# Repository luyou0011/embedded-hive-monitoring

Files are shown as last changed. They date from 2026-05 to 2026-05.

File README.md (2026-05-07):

# Entwicklung eines Embedded Systems zur automatischen Messdatenerfassung in Bienenstöcken

Diese Bachelorarbeit befasst sich mit der Entwicklung eines IoT-basierten Monitoring-Systems für Bienenvölker. Das System überwacht Klima, Gewicht und Akustik, um die Gesundheit der Bienen zu sichern und die Honigproduktion zu optimieren.

<p align="center">
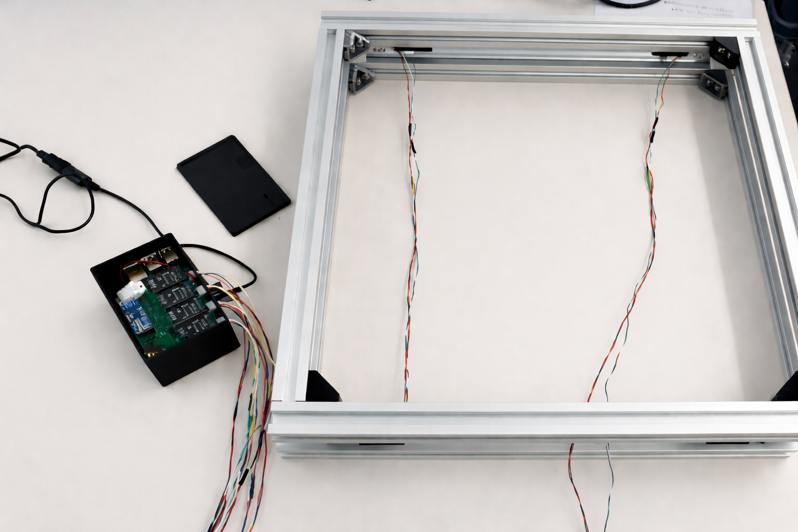
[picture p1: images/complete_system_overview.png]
Komplettes System
  
  <br>
  <em>Das fertige Monitoring-System mit Aluminiumprofil-Basis und integrierter Steuerelektronik.</em>
</p>

## Features & Funktionen
- **Multisensorik:** Präzise Echtzeit-Messung von Temperatur, Luftfeuchtigkeit (DHT22) und Gewicht (HX711).
- **Fortgeschrittene Akustik-Analyse:** Aufzeichnung von Bienengeräuschen mittels I2S-Mikrofon und digitale Frequenzfilterung (200 Hz - 1000 Hz) zur Zustandsüberwachung.
- **Energie-Monitoring:** Integrierte Überwachung des Batteriezustands (SoC) über einen ADS1115 16-Bit ADC.
- **Intelligente Datenlogik:** Event-gesteuerte Übertragung zur Reduzierung des Datenvolumens und Optimierung der Energieeffizienz.

## Hardware-Entwicklung & Design
Ein zentraler Bestandteil der Arbeit war der Übergang vom Breadboard-Prototyp zum finalen Hardware-Produkt:
- **Custom PCB:** Entwurf und Fertigung einer dedizierten Platine mit **KiCAD 8.0**.
- **Gehäusekonstruktion:** Maßgeschneidertes Schutzgehäuse, entworfen in **Autodesk Fusion**.
- **Recheneinheit:** Raspberry Pi 4B.
- **Sensorkomponenten:** DHT22 (Temperatur und Feuchtigkeit Sensor), SPH0645 (I2S Mikrofon), HX711 (24-Bit Load Cell ADC), ADS1115.

## Software & Cloud-Architektur
- **Programmiersprache:** Python (Modularer Aufbau für Sensorik und Kommunikation).
- **IoT-Integration:** 
  - **ThingSpeak:** Cloud-Visualisierung der Klima- und Gewichtsdaten.
  - **AWS IoT Core:** Sicherer MQTT-Transfer für rechenintensive Audiodaten.
- **Kommunikation:** Nutzung von TCP-Sockets für die Interprozesskommunikation.

## Mobile App (Android)
Die Überwachung erfolgt über eine maßgeschneiderte Android-App. Sie dient als mobiles Dashboard für den Imker und ermöglicht den weltweiten Zugriff auf alle Live-Daten.

<p align="center">
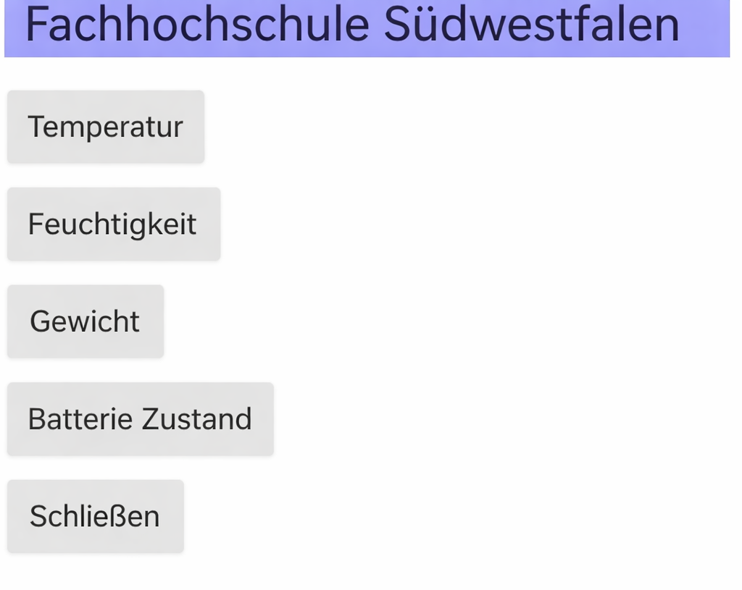
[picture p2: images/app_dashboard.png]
App Dashboard
  
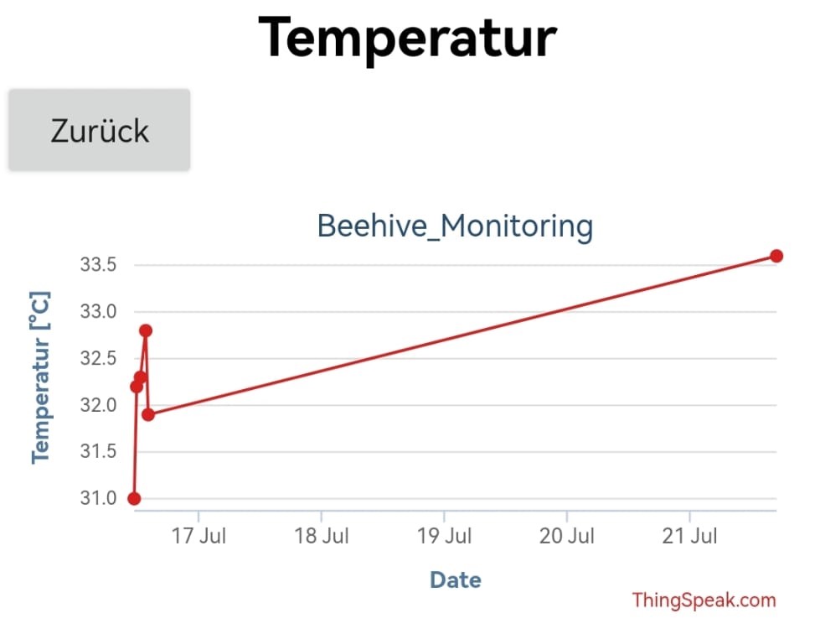
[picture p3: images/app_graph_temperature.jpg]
Temperatur Graph
  
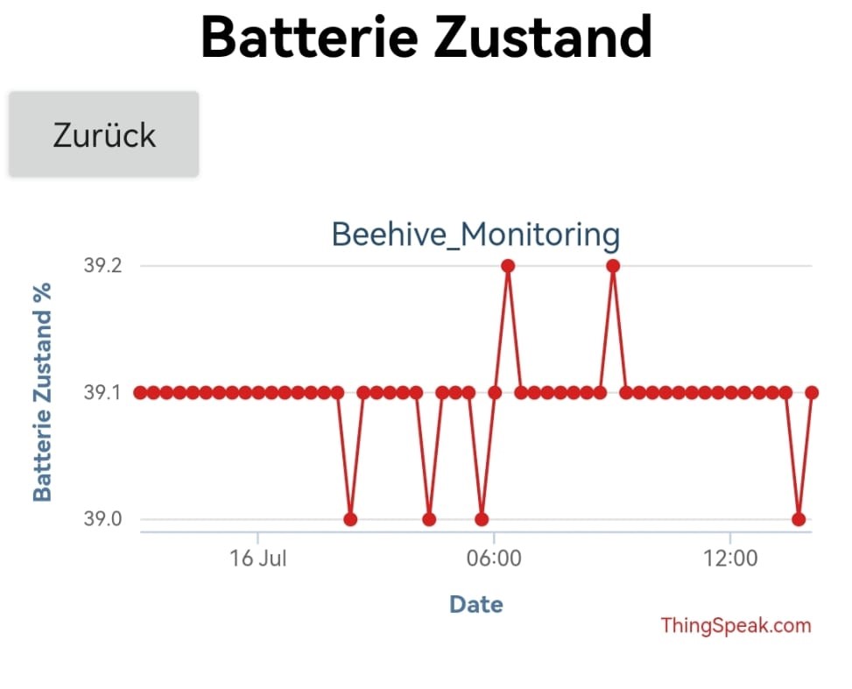
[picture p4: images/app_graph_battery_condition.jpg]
Batterie Zustand
  
  <br>
  <em>Screenshots der mobilen App: Dashboard, Temperaturverlauf und Batteriemonitoring.</em>
</p>

## Projektergebnisse
Das System wurde erfolgreich als autarke Einheit realisiert. Durch das eigene Platinenlayout wurde eine hohe Betriebssicherheit erreicht. Die Daten stehen dem Imker weltweit über Dashboards und eine Android-App zur Verfügung.

## Projektstruktur
*   `/software`: Python-Quellcode für Sensorik, Logik und Cloud-Transfer.
*   `/hardware`: Schaltpläne, PCB-Layouts (KiCAD) und 3D-Modelle (STEP).
*   `/images`: Systemfotos und App-Screenshots.

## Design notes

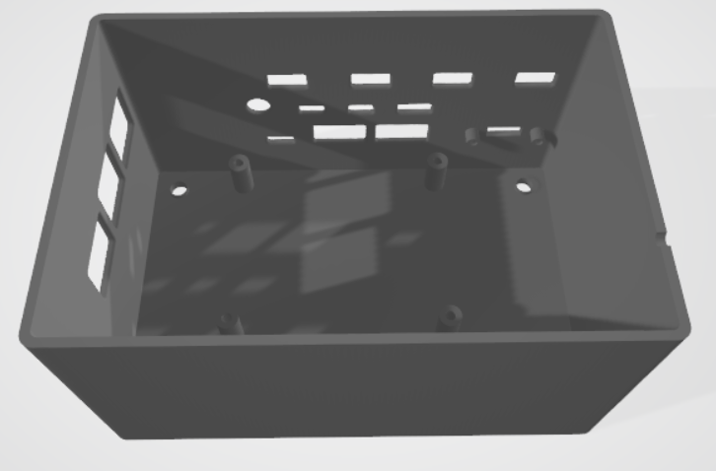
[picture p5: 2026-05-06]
hardware/3d-model/Gehäuse.png

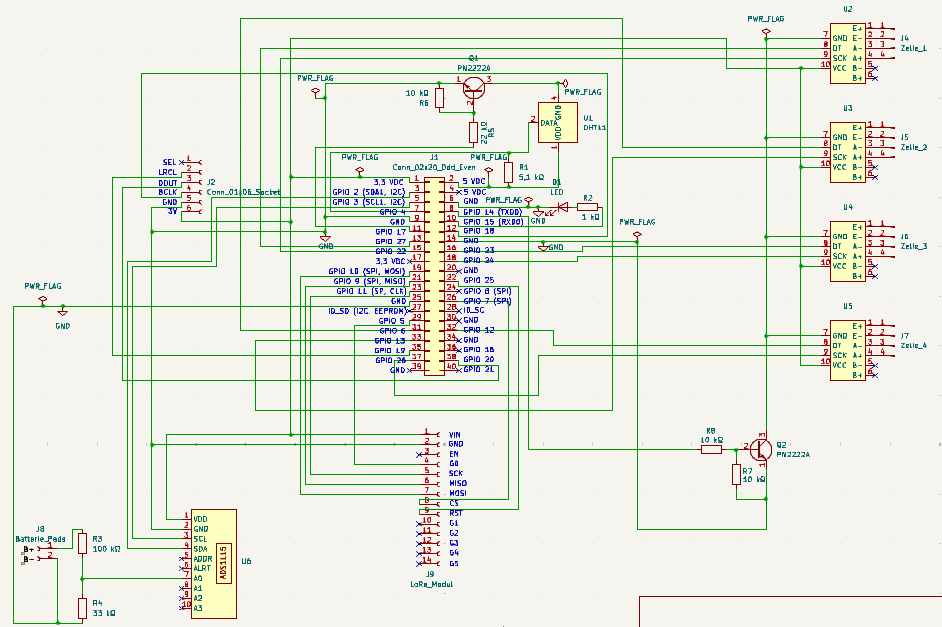
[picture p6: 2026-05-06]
hardware/pcb-design/schematic.png

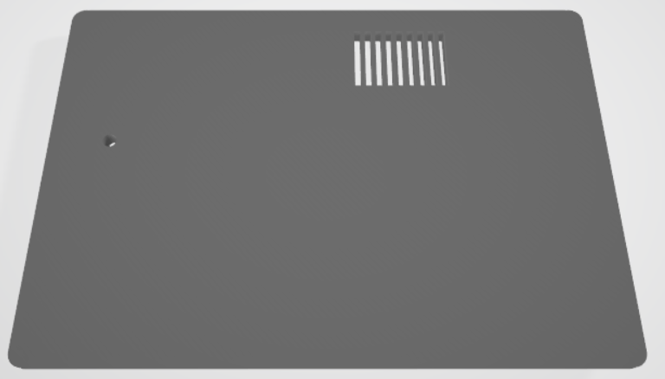
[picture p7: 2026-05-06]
hardware/3d-model/Deckel.png

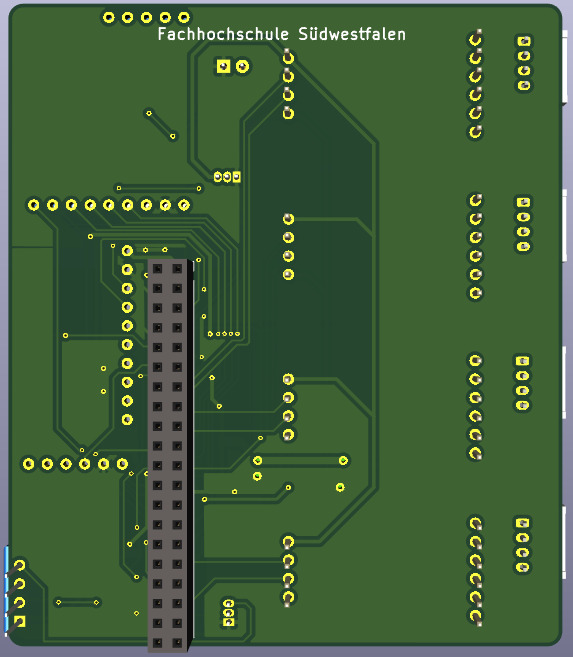
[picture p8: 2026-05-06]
hardware/pcb-design/Rückseite.png

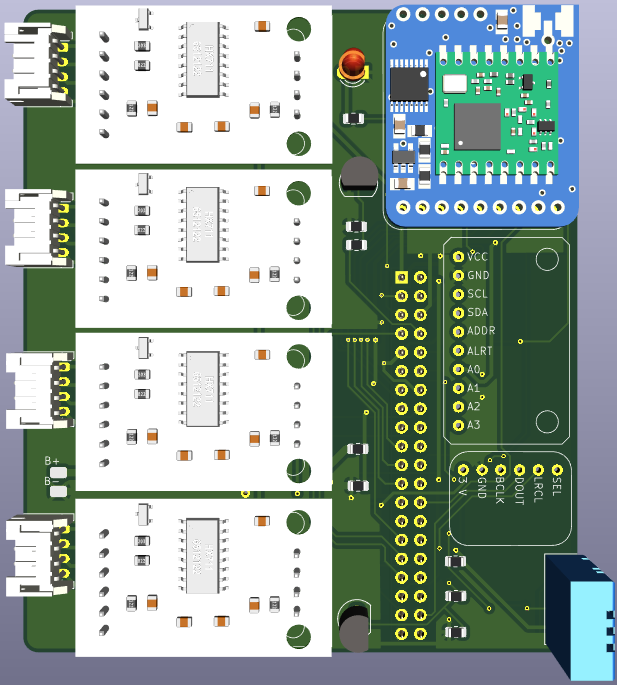
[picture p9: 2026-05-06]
hardware/pcb-design/Vorderseite.png

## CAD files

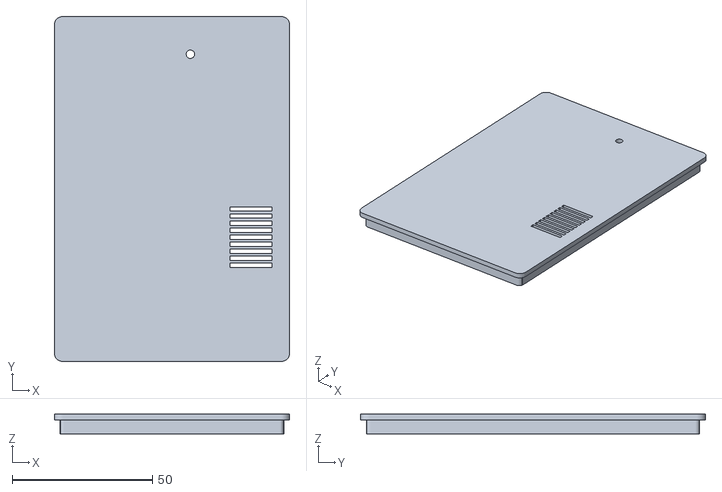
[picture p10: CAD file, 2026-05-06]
hardware/3d-model/Deckel 29.01.stl
83.9 x 122.9 x 7.00

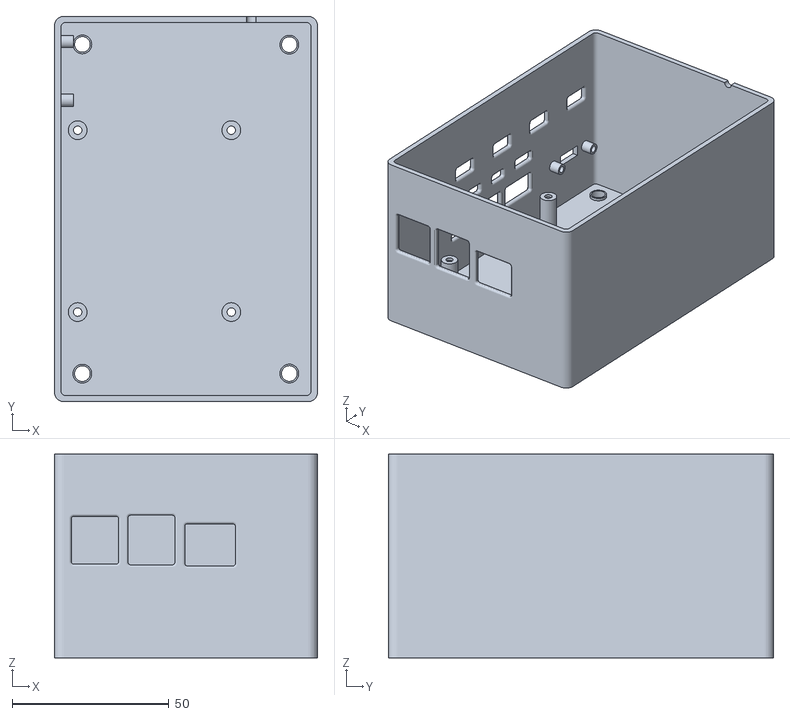
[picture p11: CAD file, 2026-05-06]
hardware/3d-model/Gehäuse 29.01.stl
83.9 x 122.9 x 65.0

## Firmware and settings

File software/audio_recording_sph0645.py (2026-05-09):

import sounddevice as sd
import wave
import time
import base64
import json
import os
import numpy as np
import math
from AWSIoTPythonSDK.MQTTLib import AWSIoTMQTTClient
from scipy.fftpack import fft
from scipy.signal import butter, lfilter
from datetime import datetime

sd.default.device = "sysdefault:CARD=sndrpigooglevoi"
sd.default.dtype = "int32"
sd.default.channels = 1


# Configuration
CHANNELS = 2
RATE = 48000  # Correct sample rate
RECORD_SECONDS = 5
BLOCK_SIZE = 100 * 1024  # Each block ~100 KB
TIMEOUT = 15
LOCAL_DIR = "/home/pi/Desktop/SPH/lokale_aufnahmen"

# AWS IoT MQTT Client setup
Client = AWSIoTMQTTClient('RPiClient')
Client.configureEndpoint('XXX.amazonaws.com', 8883)
Client.configureCredentials('/home/pi/AWS/root-ca.pem', '/home/pi/AWS/private.pem.key', '/AWS/certificate.pem.crt')

letzte_Signal = None

def Server_Signal_callback(client, userdata, message):
    global letzte_Signal
    letzte_Signal = time.time()
    print(f"Es wurde ein Signal vom Server empfangen")

def Verbinden_Mit_Dem_Server():
    try:
        Client.connect()
        print("Mit dem Server verbunden")
        Client.subscribe("Server/Signal", 1, Server_Signal_callback)
        return True
    except Exception as e:
        print(f"Verbindung zu AWS IoT fehlgeschlagen: {e}")
        return False

def Ist_Server_Online():
    if letzte_Signal and (time.time() - letzte_Signal) < TIMEOUT:
        return True
    return False

def remove_dc_offset(data):
    return data - np.mean(data)

def calculate_rms(data):
    squared_data = data ** 2
    rms = np.sqrt(np.mean(squared_data))
    return max(rms, 1e-12)  # Prevent zero or near-zero values

def calculate_peak_frequency(data, RATE):
    fft_result = np.abs(fft(data))
    half_len = len(fft_result) // 2
    freqs = np.fft.fftfreq(len(data), 1.0 / RATE)[:half_len]
    peak_freq = freqs[np.argmax(fft_result[:half_len])]
    return peak_freq

def high_pass_filter(data, cutoff, fs, order=5):
    nyquist = 0.5 * fs
    normal_cutoff = cutoff / nyquist
    b, a = butter(order, normal_cutoff, btype='high', analog=False)
    return lfilter(b, a, data)

def Event_Trigger(frames, RATE):
    audio_data = np.frombuffer(frames, dtype=np.int32)  # Correct dtype
    
    # Remove DC offset
    audio_data = remove_dc_offset(audio_data)

    # Apply high-pass filter
    filtered_audio = high_pass_filter(audio_data, cutoff=50, fs=RATE)

    # Calculate RMS and amplitude
    rms = calculate_rms(filtered_audio)
    amplitude_db = 20 * math.log10(rms)

    # Calculate peak frequency
    peak_freq = calculate_peak_frequency(filtered_audio, RATE)

    print(f"Peak Frequency: {peak_freq:.2f} Hz, Amplitude: {amplitude_db:.2f} dB")
    return peak_freq, amplitude_db

def Speichern_Audio_Datei_Als_Wave(wave_datei, frames):
    if not os.path.exists(LOCAL_DIR):
        os.makedirs(LOCAL_DIR)

    datei_pfad = os.path.join(LOCAL_DIR, wave_datei)

    try:
        with wave.open(datei_pfad, 'wb') as wf:
            wf.setnchannels(CHANNELS)
            wf.setsampwidth(4)  #32-bit audio
            wf.setframerate(RATE)
            wf.writeframes(frames)

        print(f"Aufnahme gespeichert unter {datei_pfad}")
    except Exception as e:
        print(f"Fehler beim Speichern der Datei {datei_pfad}: {e}")

def Kodieren(datei_pfad):
    try:
        with open(datei_pfad, 'rb') as f:
            audio_datei = f.read()
        return base64.b64encode(audio_datei).decode('utf-8')  # ✅ Fixed encoding
    except Exception as e:
        print(f"Die Audio-Datei konnte nicht kodiert werden: {e}")
        return None

def senden(datei_pfad):
    json_frames = Kodieren(datei_pfad)
    if json_frames is None:
        return False

    json_bytes = json_frames.encode('utf-8')
    total_blocks = (len(json_bytes) + BLOCK_SIZE - 1) // BLOCK_SIZE

    for i in range(0, len(json_bytes), BLOCK_SIZE):
        block = json_bytes[i:i + BLOCK_SIZE]
        payload = {
            "filename": os.path.basename(datei_pfad),
            "Block_Nummer": i // BLOCK_SIZE,
            "audio_data": block.decode('utf-8'),
            "Total_Blocks": total_blocks
        }
        try:
            Client.publish(topic='Bienen/Geräusche', QoS=1, payload=json.dumps(payload))
            print(f"Block {i // BLOCK_SIZE} erfolgreich gesendet")
        except Exception as e:
            print(f"Senden fehlgeschlagen: {e}")
            return False
    return True

def verarbeite_datei(wave_datei):
    datei_pfad = os.path.join(LOCAL_DIR, wave_datei)
    if senden(datei_pfad):
        os.remove(datei_pfad)
        print(f"Datei {datei_pfad} erfolgreich gesendet und gelöscht.")
    else:
        print(f"Datei {datei_pfad} konnte nicht gesendet werden.")

def Aufnehmen(wave_datei):
    try:
        print("🎙️ Aufnahme startet...")
        audio_data = sd.rec(
            int(RATE * RECORD_SECONDS),
            samplerate=RATE,
            channels=CHANNELS,
            dtype='int32'  
        )
        sd.wait()

        frames = audio_data.tobytes()
        peak_freq, amplitude_db = Event_Trigger(frames, RATE)

        if 50 <= peak_freq <= 1000 and 25 <= amplitude_db <= 110:
            print("Frequenz im Bereich, Audio wird gespeichert.")
            Speichern_Audio_Datei_Als_Wave(wave_datei, frames)
        else:
            print("Frequenz außerhalb des Bereichs, Aufnahme verworfen.")

    except Exception as e:
        print(f"Fehler bei der Aufnahme: {e}")

# Main loop
count = 1
if Verbinden_Mit_Dem_Server():
    while True:
        wave_datei = f"Aufgenommene_Audio_{count}.wav"
        Aufnehmen(wave_datei)

        if Ist_Server_Online():
            verarbeite_datei(wave_datei)

        count += 1
        time.sleep(10)
else:
    print("Verbindung zum Server fehlgeschlagen")

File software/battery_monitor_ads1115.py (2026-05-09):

import time
import Adafruit_ADS1x15
import requests
import sys
import os


sys.stdout.reconfigure(line_buffering=True)  # Forces real-time logging

# Check if the system just rebooted
if not os.path.exists("/tmp/delay_completed"):
    print("System reboot detected. Waiting 15 minutes before starting the script...", flush=True)
    time.sleep(900)  # 900 seconds = 15 minutes
    open("/tmp/delay_completed", "w").close()  # Create a file to track delay completion

# ThingSpeak API Key and URL
api_key = 'DEIN_THINGSPEAK_WRITE_API_KEY'
url = 'https://api.thingspeak.com/update'

# ADC-Instanz erstellen
adc = Adafruit_ADS1x15.ADS1115()

# Verstärkung (GAIN) einstellen
GAIN = 1  # Messbereich: ±4.096 V

# Spannungsteiler-Verhältnis berechnen (R1 = 100kΩ, R2 = 33kΩ)
divider_ratio = (100 + 33) / 33  # R1 + R2 / R2 = 133 / 33 ≈ 4.0303

def calculate_battery_percentage(voltage):
    """
    Berechnet den Batteriestand basierend auf der angegebenen Spannung und der Tabelle.
    """
    # LiPo-Spannungs-SoC-Tabelle
    voltage_soc_table = [
        (4.20, 100),
        (4.15, 95),
        (4.10, 90),
        (4.05, 85),
        (4.00, 80),
        (3.95, 75),
        (3.90, 70),
        (3.85, 65),
        (3.80, 60),
        (3.75, 55),
        (3.70, 50),
        (3.65, 45),
        (3.60, 40),
        (3.55, 35),
        (3.50, 30),
        (3.45, 25),
        (3.40, 20),
        (3.35, 15),
        (3.30, 10),
        (3.25, 5),
        (3.20, 0)
    ]

    # Werte vergleichen und interpolieren
    for i in range(len(voltage_soc_table) - 1):
        high_voltage, high_soc = voltage_soc_table[i]
        low_voltage, low_soc = voltage_soc_table[i + 1]

        if high_voltage >= voltage >= low_voltage:
            # Lineare Interpolation zwischen den Punkten
            percentage = high_soc + (voltage - high_voltage) * (low_soc - high_soc) / (low_voltage - high_voltage)
            return round(percentage, 1)

    # Falls Spannung außerhalb des Bereichs liegt
    if voltage > 4.20:
        return 100.0
    elif voltage < 3.20:
        return 0.0

print('[Drücken Sie Strg+C, um das Skript zu beenden]', flush=True)
try:
    # Hauptprogrammschleife
    while True:
        # Rohwert von Kanal 0 lesen
        raw_value = adc.read_adc(0, gain=GAIN)

        # Rohwert in Spannung umrechnen
        V_ADC = (raw_value * 4.096) / 32767  # GAIN = 1 → ±4.096 V

        # Batteriespannung berechnen
        V_Battery = V_ADC * divider_ratio

        # Batterieprozentsatz berechnen
        battery_percentage = calculate_battery_percentage(V_Battery)

        # Ergebnisse ausgeben
        print(f"ADC Spannung: {V_ADC:.3f} V", flush=True)
        print(f"Batterie Spannung: {V_Battery:.3f} V", flush=True)
        print(f"Batterie Ladezustand: {battery_percentage:.1f}%", flush=True)
        
        # Daten an ThingSpeak senden
        try:
            data = {
                'api_key': api_key,
                'field4': battery_percentage  # Sends battery percentage to ThingSpeak Field 4
            }
            response = requests.post(url, data=data)

            if response.status_code == 200:
                print("Battery status sent successfully to ThingSpeak.", flush=True)
            else:
                print(f"Error sending data: {response.status_code}", flush=True)

        except requests.exceptions.RequestException as e:
            print(f"Network error: {e}", flush=True)
        time.sleep(1200)

except KeyboardInterrupt:
    print('Skript beendet!', flush=True)

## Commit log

2026-05-05 Add Python scripts for sensors, audio recording and AWS IoT cloud transfer
2026-05-06 Create pcb-design
2026-05-06 Add hardware directory structure for PCB design and 3D models
    [Beeive Monitoring-B_Cu.gbr, Beeive Monitoring-B_Mask.gbr, Beeive Monitoring-B_Paste.gbr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]
2026-05-09 Add Python scripts for sensor data acquisition and IoT cloud transfer
